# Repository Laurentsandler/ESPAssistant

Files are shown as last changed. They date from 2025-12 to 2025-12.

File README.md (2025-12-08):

# ESPAssistant

A small portable AI Assistant computer built with ESP32.

## Description

This compact computer is equipped with an ESP32 Seed Studio microcontroller, featuring three buttons, a small OLED display, and an INMP441 microphone. It connects to a smartphone's hotspot. Upon pressing and holding one of the buttons, it records audio, which is then transcribed using the Groq Whisper API and sent to the Groq Llama 3.1 API for a chat response. The response is displayed on the OLED screen.

## My motiviation:
So, I wanted a small little computer that will help me throughout the day.

I wanted it to have AI. And also an input using a microphone and some buttons and a small display.

I am in school, so I wanted it to help me track assignments as they come in from my teachers. So, I want to when I press a button, it will record my voice, transcribe it, and then have it sent to a custom website to be added to my assignments or notes, etc.

## Hardware Design

The custom PCB was designed using EasyEDA. Below are the 3D renders and PCB layout:

### PCB Layout

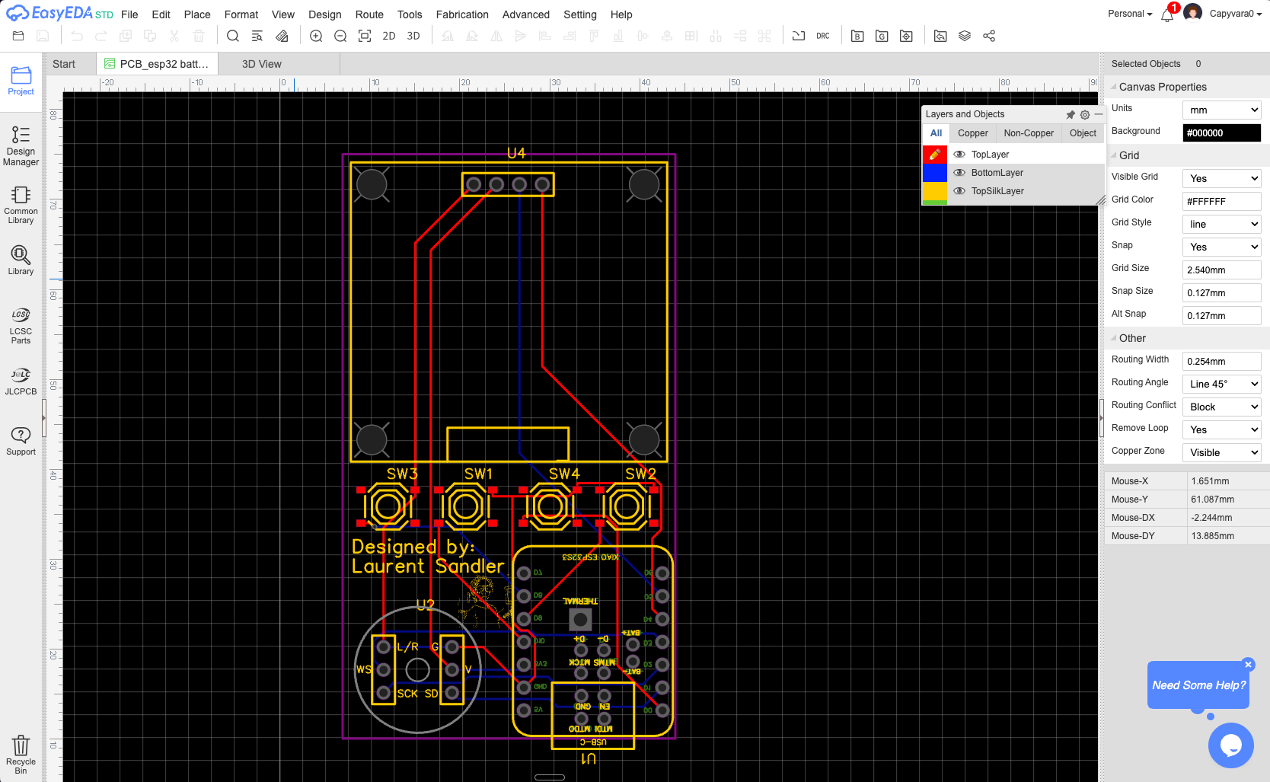
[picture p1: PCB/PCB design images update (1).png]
PCB view


### 3D Renders

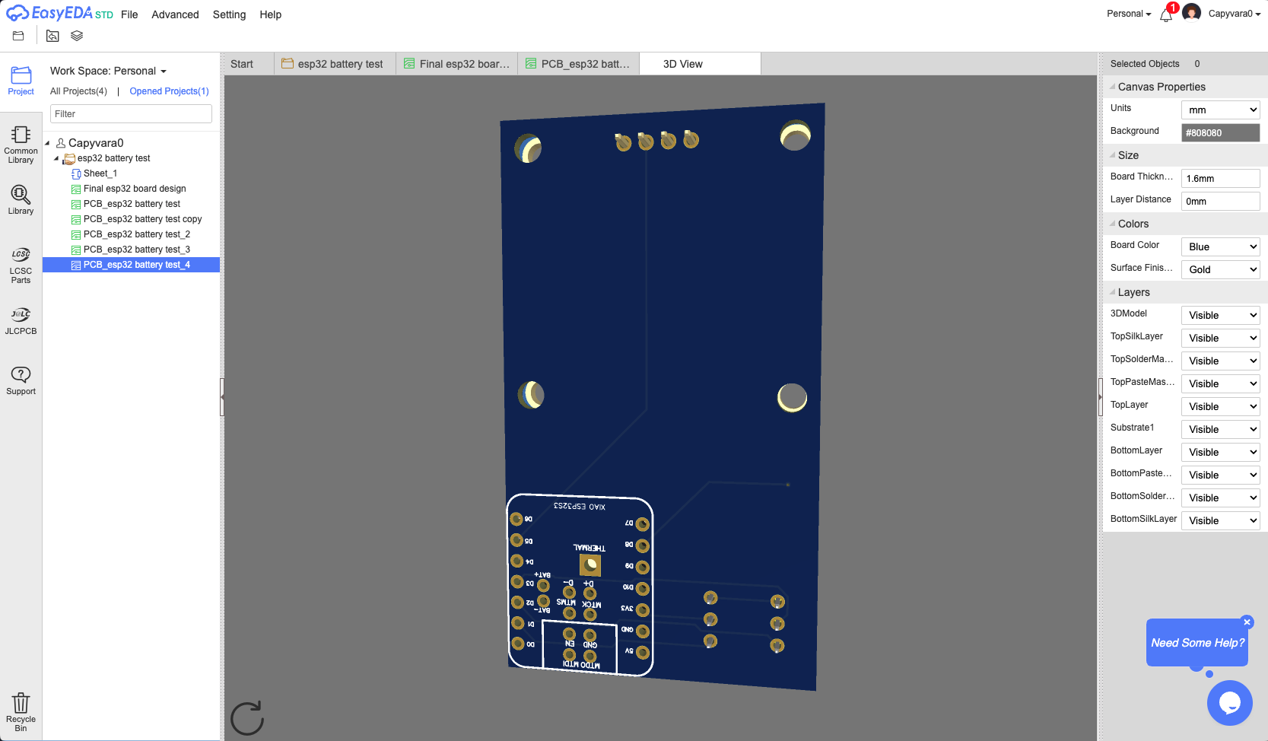
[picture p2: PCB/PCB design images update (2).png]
PCB 3D View - Back Angle


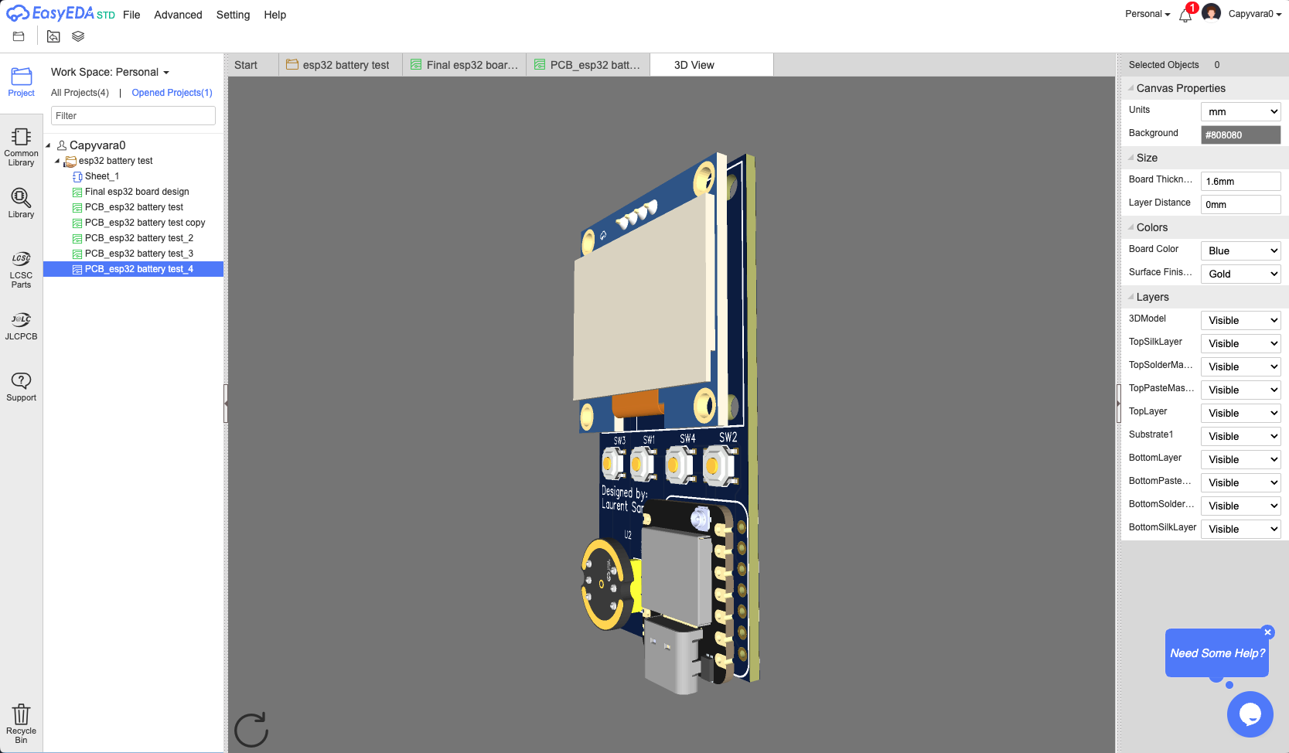
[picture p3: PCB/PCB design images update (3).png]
PCB 3D View - Side


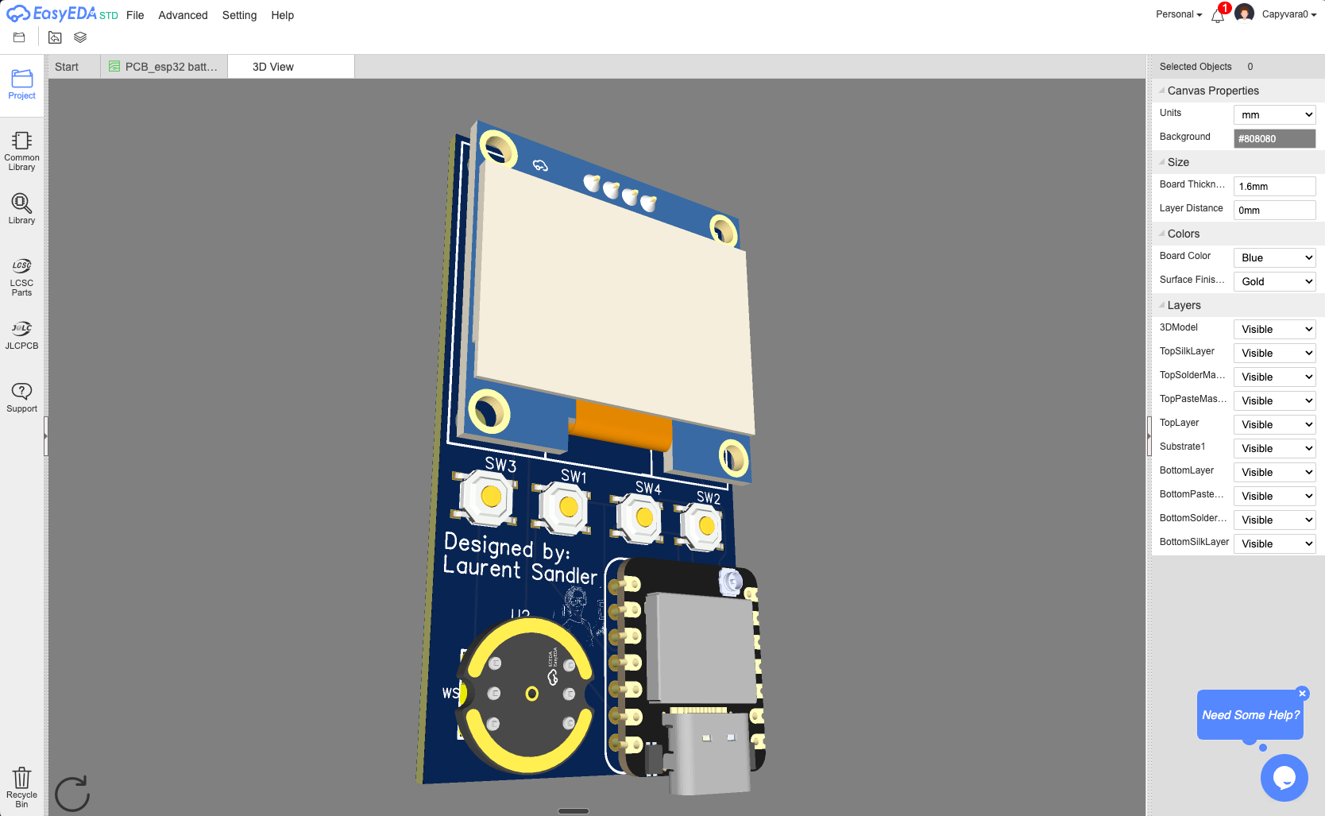
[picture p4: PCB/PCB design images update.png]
PCB 3D View - Front


## Features

- **Voice Recording**: Press and hold to record audio via INMP441 I2S microphone
- **Speech-to-Text**: Transcription via Groq Whisper API
- **AI Chat**: Responses powered by Llama 3.1 via Groq API
- **OLED Display**: 128x64 SH1106/SSD1306 display with modern UI
- **Weather App**: Real-time weather with geolocation
- **Reaction Game**: Fun reaction time game
- **Assignment Tracker**: Voice-record assignments and save to Supabase
- **Screensaver**: Analog clock with digital time display
- **Web Server**: Access recorded audio via browser

## Hardware Requirements

| Component | Specification | Pin Connection |
|---|---|---|
| Microcontroller | ESP32 (Seed Studio) | - |
| Microphone | INMP441 I2S | WS=4, SD=2, SCK=3 |
| Display | SH1106/SSD1306 128x64 OLED | SDA=5, SCL=6 |
| Button 1 (Main) | Momentary push button | GPIO 7 |
| Button 2 (Scroll) | Momentary push button | GPIO 8 |
| Button 3 (Assignment) | Momentary push button | GPIO 9 |
| Button 4 (Extra) | Momentary push button | GPIO 1 |

## Software Dependencies

Install these libraries via Arduino IDE Library Manager:
- WiFi (built-in)
- WiFiClientSecure (built-in)
- HTTPClient (built-in)
- WebServer (built-in)
- ESPmDNS (built-in)
- U8g2lib
- Wire (built-in)

## Configuration

Before uploading, edit the following in `Firmware/sketch.ino`:

```cpp
const char* WIFI_SSID = "YOUR_WIFI_SSID";
const char* WIFI_PASS = "YOUR_WIFI_PASSWORD";
const char* GROQ_API_KEY = "YOUR_GROQ_API_KEY";

const char* SUPABASE_URL = "YOUR_SUPABASE_URL";
const char* SUPABASE_ANON_KEY = "YOUR_SUPABASE_ANON_KEY";
const char* SUPABASE_USER_ID = "YOUR_SUPABASE_USER_ID";
const char* SUPABASE_SERVICE_KEY = "YOUR_SUPABASE_SERVICE_KEY";
```

## Usage

### Menu Navigation
- **Short press Button 1 (GPIO 7)**: Navigate left in menu
- **Short press Button 2 (GPIO 8)**: Navigate right in menu
- **Long press Button 1**: Select/Enter app

### AI Mode
- **Hold Button 1**: Record audio
- **Release**: Transcribe and get AI response
- **Button 2**: Scroll through long responses
- **Long press Button 2**: Return to menu

### Weather Mode
- Automatically fetches weather based on IP geolocation
- **Short press Button 2**: Force refresh
- **Long press Button 1**: Return to menu

### Assignment Mode
- **Hold Button 3 (GPIO 9)**: Record assignment details
- Voice input is parsed by AI and saved to Supabase

## Web Interface

After connecting to WiFi, access the web interface at:
- `http://<ESP32_IP>/` - Home page
- `http://<ESP32_IP>/audio.wav` - Download last recording
- `http://esp32.local/audio.wav` - Via mDNS (if supported)

## API Services Used

- **Groq API**: Speech-to-text (Whisper) and chat (Llama 3.1)
- **Open-Meteo API**: Weather data
- **ipapi.co**: IP-based geolocation
- **Supabase**: Database for assignment storage

## Case
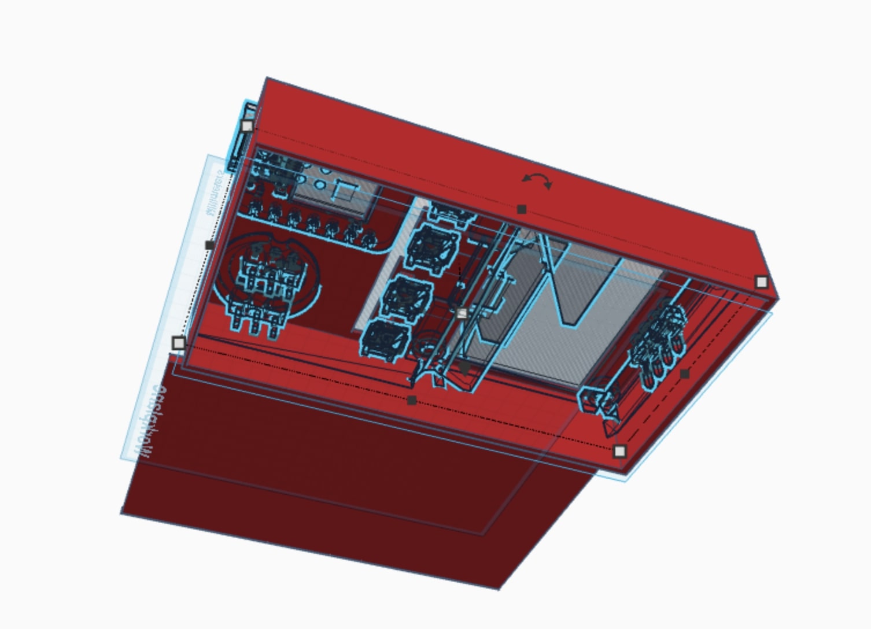
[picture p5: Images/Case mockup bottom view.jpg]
Case mockup bottom view.jpg

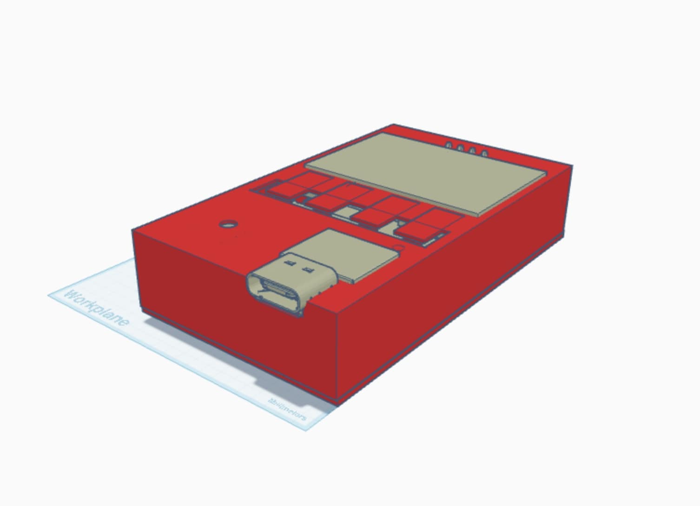
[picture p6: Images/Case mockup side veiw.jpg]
Case mockup side veiw.jpg

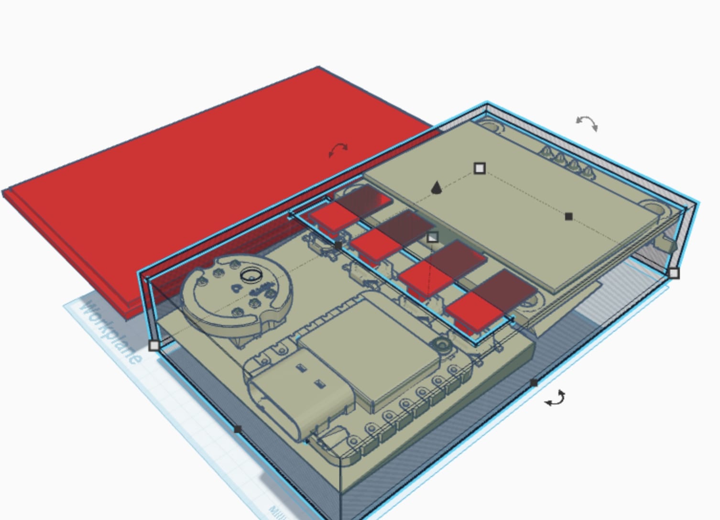
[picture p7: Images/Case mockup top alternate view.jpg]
Case mockup top alternate view.jpg

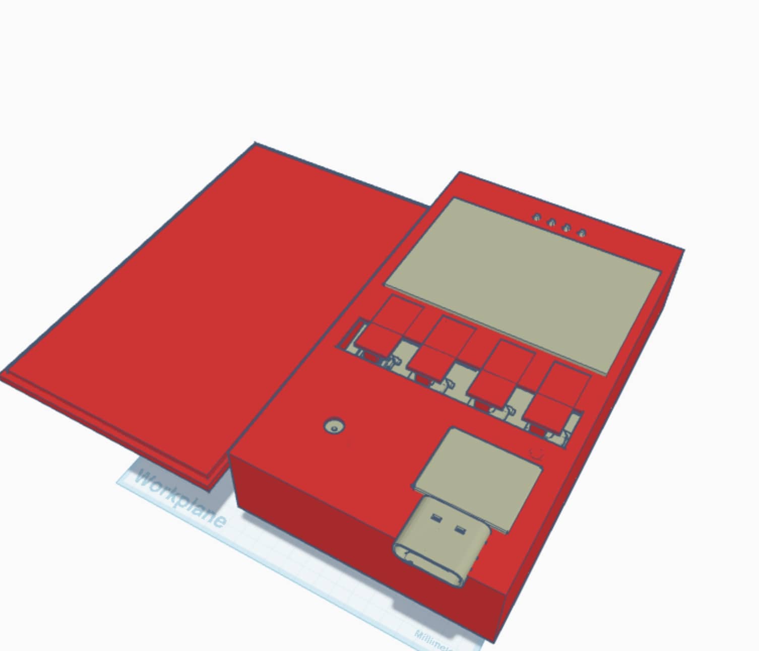
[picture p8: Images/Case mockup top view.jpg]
Case mockup top view.jpg


## Bom: 
| Component | Footprint | Quantity | Supplier Part Number | Price | Link |
| --- | --- | --- | --- | ----- | --- |
| OLED SD130 | OLED-TH12864 | 1 | C9900014198 | 10€ | [https://amzn.eu/d/837vRA1](https://amzn.eu/d/837vRA1) |
| INMP441-MEMS-I2S-MIC-MODULE | INMP441-MEMS-I2S-MIC-MODULE | 1 | N/A | 7€ | [https://amzn.eu/d/0Qtf1CE](https://amzn.eu/d/0Qtf1CE) |
| SEEED XIAO ESP32S3 | SEEED STUDIO XIAO_S3 BY LAURENT | 1 | N/A | 20€ | [https://amzn.eu/d/1FE54ig](https://amzn.eu/d/1FE54ig) |
| TS-1187A-B-A-B | SW-SMD_4P-L5.1-W5.1-P3.70-LS6.5-TL_H1.5 | 4 | C318884 | 0.32€ | [https://www.lcsc.com/product-detail/C318884.html?s_z=n_TS-1187A-B-A-B](https://www.lcsc.com/product-detail/C318884.html?s_z=n_TS-1187A-B-A-B) |
| 500175140 PogoPin Connector | N/A | 1 | B09STS5YZX | 7.90€ | [https://amzn.eu/d/2DIAPW8](https://amzn.eu/d/2DIAPW8) |

## License

MIT License

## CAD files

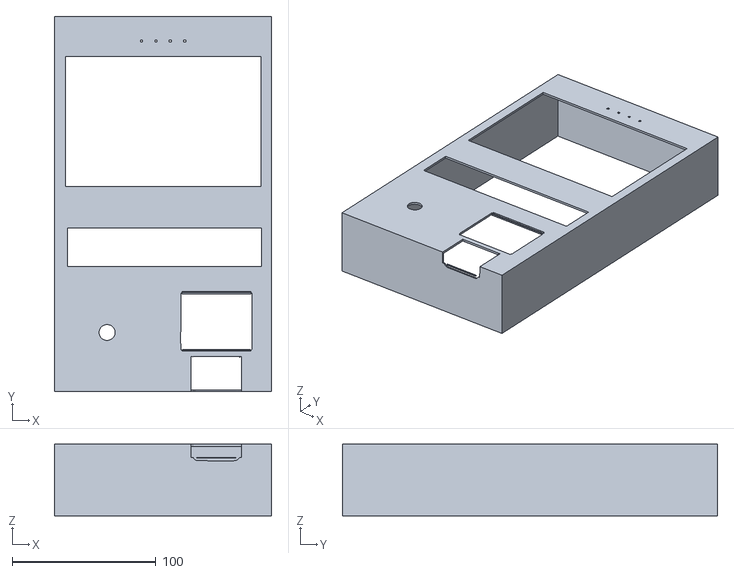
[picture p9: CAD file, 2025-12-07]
CAD/Case with space for battery.stl
151.0 x 261.0 x 50.0

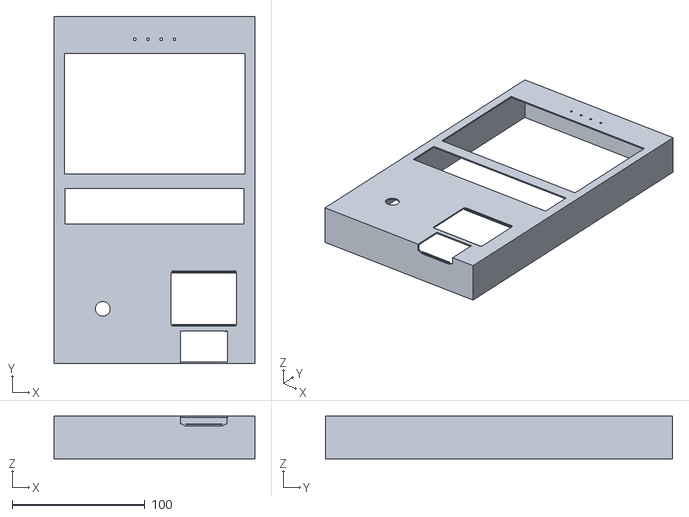
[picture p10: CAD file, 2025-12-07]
CAD/Case.stl
151.0 x 261.0 x 32.0

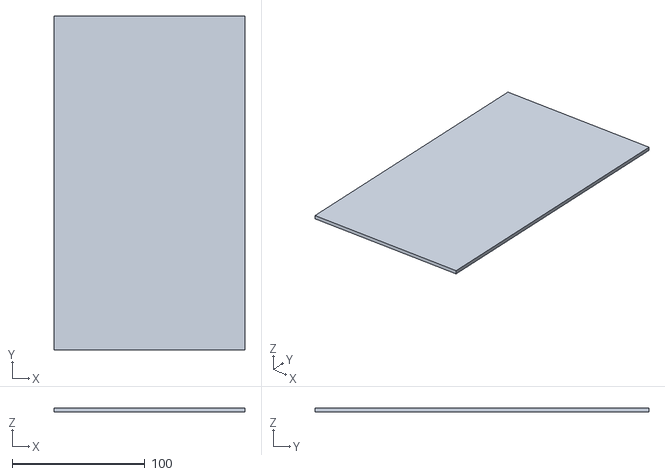
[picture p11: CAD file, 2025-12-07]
CAD/Case lid.stl
144.0 x 252.0 x 3.00

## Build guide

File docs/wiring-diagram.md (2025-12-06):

# Wiring Diagram

This document describes the hardware connections for the ESP32 AI Assistant.

## Component Connections

### INMP441 I2S Microphone
Connect the INMP441 microphone to the ESP32 as follows:

```
INMP441 Pin  →  ESP32 Pin
--------------------------
VDD          →  3.3V
GND          →  GND
WS (Word Select) → GPIO 4
SD (Serial Data) → GPIO 2
SCK (Serial Clock) → GPIO 3
L/R          →  GND (for left channel)
```

### SH1106/SSD1306 OLED Display (I2C)
Connect the 128x64 OLED display to the ESP32:

```
OLED Pin  →  ESP32 Pin
-----------------------
VCC       →  3.3V
GND       →  GND
SDA       →  GPIO 5
SCL       →  GPIO 6
```

### Buttons
Connect momentary push buttons with internal pull-up resistors:

```
Button          →  ESP32 Pin  →  Function
-------------------------------------------
Button 1        →  GPIO 7     →  Main button (menu navigation, recording)
Button 2        →  GPIO 8     →  Scroll button (menu navigation, scrolling)
Button 3        →  GPIO 9     →  Assignment button (voice assignments)
Button 4        →  GPIO 1     →  Extra button (reserved for future use)
```

Each button should connect:
- One side to the GPIO pin
- Other side to GND
- The ESP32 will use INPUT_PULLUP mode (no external resistor needed)

## Circuit Diagram (ASCII Art)

```
                    ┌─────────────────────┐
                    │                     │
    INMP441         │     ESP32-C3        │        SH1106 OLED
    ┌──────┐        │   Seed Studio       │         ┌────────┐
    │ VDD  ├────────┤ 3.3V                │         │  VCC   │
    │ GND  ├────────┤ GND         GPIO 5  ├─────────┤  SDA   │
    │ WS   ├────────┤ GPIO 4      GPIO 6  ├─────────┤  SCL   │
    │ SD   ├────────┤ GPIO 2              │         │  GND   │
    │ SCK  ├────────┤ GPIO 3              │         └────────┘
    │ L/R  ├────┐   │                     │
    └──────┘    │   │                     │
                │   │                     │
               GND  │                     │
                    │                     │
                    │  GPIO 7 ├───[BTN1]──┤ GND
                    │  GPIO 8 ├───[BTN2]──┤ GND
                    │  GPIO 9 ├───[BTN3]──┤ GND
                    │  GPIO 1 ├───[BTN4]──┤ GND
                    │                     │
                    └─────────────────────┘
```

## Power Supply

- The ESP32 can be powered via USB-C (if your board has USB-C) or Micro-USB
- All components (INMP441, OLED) are powered from the ESP32's 3.3V regulator
- Ensure your power supply can provide at least 500mA for stable operation

## Notes

- The INMP441 L/R pin is connected to GND to select the left channel
- All buttons use the ESP32's internal pull-up resistors (INPUT_PULLUP mode)
- I2C address for the OLED is typically 0x3C (defined in the code)
- Ensure proper grounding - connect all GND pins together

## Testing the Hardware

After wiring, you can test each component:

1. **OLED Display**: Upload the sketch and check if the initialization screen appears
2. **Buttons**: Press each button and check the Serial Monitor for debug output
3. **Microphone**: Try recording in AI mode and check the serial output for sample count
4. **WiFi**: Verify connection on the OLED and check the IP address on Serial Monitor

## Troubleshooting

| Issue | Possible Cause | Solution |
|---|---|---|
| OLED not displaying | Wrong I2C address or wiring | Check I2C scanner, verify SDA/SCL pins |
| No audio recording | Incorrect I2S pins | Verify WS, SD, SCK connections |
| Buttons not responding | Pull-up not enabled | Check pinMode(pin, INPUT_PULLUP) in code |
| WiFi not connecting | Wrong credentials | Update WIFI_SSID and WIFI_PASS |

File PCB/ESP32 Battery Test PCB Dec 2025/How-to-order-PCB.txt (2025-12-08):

How to Order PCB

Please refer to:
https://docs.easyeda.com/en/PCB/Order-PCB

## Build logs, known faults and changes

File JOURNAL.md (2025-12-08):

# Development Journal

**Total Time Spent: 16.9 hours**

---

## December 7, 2025
I designed a case and included space for a small battery, a couple of millimeters thick, and some flexible pieces on the case to push the buttons. Some photographs are attached below. And I added the STL files to the repository.

**Files added:**
- `Case with space for battery.stl`
- `Case lid.stl`
- Case mockup images in the Images folder

Case mockup bottom view
Case mockup side view
Case mockup top alternate view
Case mockup top view

---

## ~5 days ago - Finalizing and getting PCB manufactured (2.0 hours)

I finalized the PCB I added a fourth button and made all of the buttons low-profile ones. And remove the expandable I/O. I considered using a small I/O expansion chip, but since this was my first time making a PCB, I wanted it to be as simple as possible. So I decided against that.

I should get the PCB in 5-6 days. Once I get it, I'll solder on the components. In the meantime, I'll need to finish writing the code for it and designing a custom UI.

---

## ~18 days ago - Tested circuit with new board (1.3 hours)

Today my Seeed Studio XIAO ESP32S3 board finally arrived. It came in this small little tiny package. So I connected it to all my components on a breadboard and uploaded the code. But some things didn't work. Turns out the seeed studio board has a different configuration than my other ESP32 dev kit. So I changed that, and once I changed it, everything worked without problems. Also, I noticed that the upload speed on this board is way faster. It can upload stuff a lot faster than my other board.

---

## ~19 days ago - Redesigned the PCB (2.0 hours)

Today I decided to redesign the PCB a little bit because first I realized that it was gonna be pretty hard to directly solder on the microcontroller onto the PCB instead of just using pins. So I redesigned it to use holes where I can put pins in, and then the microcontroller on top to connect it to the PCB. Also, I got some inspiration from another mini computer I saw on Instagram, they also had a Kick starter:

I saw that it has really easy expandable gpio at the top, which I thought would be really nice to have incase i wanted to connect some servos or maybe a temp/humidity sensor. I wanted to use a right angled female socket connector, but sadly jlcpcba did not have any in their library of parts, and I didn't want to solder this one on myself. So I settled on a low-profile flat design. Which JLC PCBA had in stock.

I will definitely take more inspiration from this really cool product. Maybe I'll add the little pogo pin connector at the back.

---

## ~20 days ago - Designing the PCB (4.0 hours)

While the component was shipping, I set out to design my PCB so the whole construction would be smaller. I used easyeda to design the PCB.

Once I get the small microcontroller and test out the circuit on the breadboard and make sure it works, I will have JLC PCB manufacture the PCB.

---

## ~20 days ago - Researching for smaller components (0.5 hours)

Although this design worked, it was way too big to be practical. So I wanted to make it a lot smaller, but with my current ESP32 dev board and my current setup, it was just too big.

So I set out to find a smaller microcontroller.

I researched for a small esp32 microcontroller that I can use, as I am familiar with esp32 boards. I found the Seeed Studio XIAO ESP32 S3 board, it is really small! I found out that it has a built in charging circut, so I will not need an external one, thats good news I planned that the parts I will need are as follows: - A small INMP441 microphone - A small 3.9 diagonal OLED screen - Three small buttons I already have all of these components. Except the microcontroller which I ordered on Amazon.
---

## ~20 days ago - Designed and 3D printed prototype (2.0 hours)

I wanted to test how the prototype worked in the real world, I designed a case for it in on shape. I had put all the components in the case once I 3D printed it and took it with me on my day. It was really useful and without stopping, the battery lasted about 11.5 hours, so
the concept was proven.
---

## ~20 days ago - Built Large prototype (5.0 hours)

Built a working prototype using the parts I already had, and I then programmed it. It has:

A small battery
A PMS board
A microphone
Two buttons
An OLED display
An ESP32 dev board All connected to a proto board.
It successfully recorded my speech, transcribed it, sent it to AI, and then showed me the response back.

---

## ~20 days ago - Making the idea (0.1 hours)

So, I wanted a small little computer that will help me throughout the day.

I wanted it to have AI. And also an input using a microphone and some buttons and a small display.

I am in school, so I wanted it to help me track assignments as they come in from my teachers. So, I want to when I press a button, it will record my voice, transcribe it, and then have it sent to a custom website to be added to my assignments or notes, etc.

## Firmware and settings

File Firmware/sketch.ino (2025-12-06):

/* ESP32 I2S Mic -> Groq Whisper -> Groq Chat -> OLED
  Includes web server for audio playback.
  Hardware:
  - I2S mic (INMP441): WS=4, SD=2, SCK=3
  - OLED SH1106/SSD1306 I2C: SDA=5, SCL=6 (128x64)
  - Button on pin 7 (INPUT_PULLUP)
  - Button on pin 8 (scroll)
  - Button on pin 9 (assignment)
  - Button on pin 1 (extra)
*/

#include <WiFi.h>
#include <WiFiClientSecure.h>
#include <HTTPClient.h>
#include <WebServer.h>
#include <ESPmDNS.h>

#include <driver/i2s.h>
#include <Wire.h>
#include <U8g2lib.h>
#include <stdlib.h>
#include <time.h>
#include <math.h>

// --------- USER CONFIG ----------
const char* WIFI_SSID = "YOUR_WIFI_SSID";
const char* WIFI_PASS = "YOUR_WIFI_PASSWORD";
const char* GROQ_API_KEY = "YOUR_GROQ_API_KEY";

const char* TRANSCRIBE_MODEL = "whisper-large-v3";
const char* CHAT_MODEL = "llama-3.1-8b-instant";

// Supabase config - REPLACE WITH YOUR VALUES!
const char* SUPABASE_URL = "YOUR_SUPABASE_URL";
const char* SUPABASE_ANON_KEY = "YOUR_SUPABASE_ANON_KEY";
const char* SUPABASE_USER_ID = "YOUR_SUPABASE_USER_ID";
const char* SUPABASE_SERVICE_KEY = "YOUR_SUPABASE_SERVICE_KEY";

// Pin definitions
#define I2S_WS 4
#define I2S_SD 2
#define I2S_SCK 3
#define BUTTON_PIN 7
#define BUTTON_SCROLL_PIN 8
#define BUTTON_ASSIGNMENT_PIN 9
#define BUTTON_EXTRA_PIN 1

#define SCREEN_WIDTH 128
#define SCREEN_HEIGHT 64
#define OLED_SDA_PIN 5
#define OLED_SCL_PIN 6
#define OLED_ADDR 0x3C

// UI layout constants
static const int UI_STATUS_H = 12;
static const int UI_BOTTOM_TAB_H = 16;
static const int UI_MARGIN = 4;

// NTP/Time configuration (set to Europe/Paris for Marseille: CET/CEST with DST)
const char* NTP_SERVER_1 = "pool.ntp.org";
const char* NTP_SERVER_2 = "time.nist.gov";
const char* TZ_INFO = "CET-1CEST,M3.5.0/2,M10.5.0/3";

// Create display object for SH1106
U8G2_SH1106_128X64_NONAME_F_HW_I2C u8g2(U8G2_R0, U8X8_PIN_NONE, OLED_SCL_PIN, OLED_SDA_PIN);

// I2S configuration
#define I2S_PORT I2S_NUM_0
#define SAMPLE_RATE 16000
#define BITS_PER_SAMPLE I2S_BITS_PER_SAMPLE_32BIT
#define DMA_BUF_COUNT 8
#define DMA_BUF_LEN 1024

// Recording buffer
const int MAX_RECORD_TIME_MS = 10000;
const int MAX_RECORD_SAMPLES = (SAMPLE_RATE * MAX_RECORD_TIME_MS) / 1000;
int16_t* audioBuffer = nullptr;
int audioSampleCount = 0;

// Web server
WebServer server(80);

// App states
enum AppMode {
  MODE_MENU,
  MODE_AI,
  MODE_WEATHER,
  MODE_ASSIGNMENTS,
  MODE_GAME,
  MODE_SCREENSAVER
};

AppMode currentMode = MODE_SCREENSAVER;
int menuSelection = 0;
const int MENU_ITEMS = 5;
const char* menuLabels[] = {"AI", "Weather", "Assign", "Game", "Clock"};

// AI response storage
String aiResponse = "";
int responseScrollOffset = 0;

// Weather data
String weatherLocation = "";
String weatherTemp = "";
String weatherCondition = "";
unsigned long lastWeatherUpdate = 0;

// Game state
unsigned long gameStartTime = 0;
unsigned long gameReactionTime = 0;
bool gameWaitingForPress = false;

// Assignment recording
bool recordingAssignment = false;

// Button debouncing
unsigned long lastButtonPress = 0;
unsigned long lastScrollPress = 0;
unsigned long lastAssignmentPress = 0;
const int DEBOUNCE_DELAY = 50;
const int LONG_PRESS_DELAY = 500;

// Screensaver
unsigned long lastActivityTime = 0;
const unsigned long SCREENSAVER_TIMEOUT = 60000; // 1 minute

// Function declarations
void setupI2S();
void setupWiFi();
void setupWebServer();
void setupDisplay();
void setupNTP();
void recordAudio();
String transcribeAudio();
String getChatResponse(String userMessage);
void updateWeather();
void fetchWeatherData();
void startReactionGame();
void handleReactionPress();
void saveAssignment(String assignmentText);
void drawMenu();
void drawAIMode();
void drawWeatherMode();
void drawAssignmentMode();
void drawGameMode();
void drawScreensaver();
void drawStatusBar();
void checkButtons();
void returnToMenu();
String urlEncode(String str);
String createMultipartBoundary();
String jsonEscape(String str);

void setup() {
  Serial.begin(115200);
  delay(1000);
  Serial.println("ESP32 AI Assistant Starting...");

  // Initialize buttons
  pinMode(BUTTON_PIN, INPUT_PULLUP);
  pinMode(BUTTON_SCROLL_PIN, INPUT_PULLUP);
  pinMode(BUTTON_ASSIGNMENT_PIN, INPUT_PULLUP);
  pinMode(BUTTON_EXTRA_PIN, INPUT_PULLUP);

  // Initialize display
  setupDisplay();
  u8g2.clearBuffer();
  u8g2.setFont(u8g2_font_6x10_tr);
  u8g2.drawStr(0, 20, "Initializing...");
  u8g2.sendBuffer();

  // Allocate audio buffer with overflow protection
  size_t bufferSize = (size_t)MAX_RECORD_SAMPLES * sizeof(int16_t);
  // Check for overflow: if the result is smaller than MAX_RECORD_SAMPLES, overflow occurred
  if (bufferSize / sizeof(int16_t) != MAX_RECORD_SAMPLES) {
    Serial.println("Buffer size overflow detected!");
    u8g2.clearBuffer();
    u8g2.drawStr(0, 20, "Config Error!");
    u8g2.sendBuffer();
    while (1) delay(1000);
  }
  audioBuffer = (int16_t*)malloc(bufferSize);
  if (!audioBuffer) {
    Serial.println("Failed to allocate audio buffer!");
    u8g2.clearBuffer();
    u8g2.drawStr(0, 20, "Memory Error!");
    u8g2.sendBuffer();
    while (1) delay(1000);
  }

  // Setup I2S
  setupI2S();

  // Connect to WiFi
  setupWiFi();

  // Setup NTP
  setupNTP();

  // Setup web server
  setupWebServer();

  // Start in screensaver mode
  currentMode = MODE_SCREENSAVER;
  lastActivityTime = millis();

  Serial.println("Setup complete!");
}

void loop() {
  server.handleClient();
  checkButtons();

  // Auto-enter screensaver after timeout
  if (currentMode != MODE_SCREENSAVER && (millis() - lastActivityTime > SCREENSAVER_TIMEOUT)) {
    currentMode = MODE_SCREENSAVER;
  }

  // Draw current mode
  u8g2.clearBuffer();
  
  switch (currentMode) {
    case MODE_MENU:
      drawMenu();
      break;
    case MODE_AI:
      drawAIMode();
      break;
    case MODE_WEATHER:
      drawWeatherMode();
      break;
    case MODE_ASSIGNMENTS:
      drawAssignmentMode();
      break;
    case MODE_GAME:
      drawGameMode();
      break;
    case MODE_SCREENSAVER:
      drawScreensaver();
      break;
  }

  u8g2.sendBuffer();
  delay(10);
}

void setupDisplay() {
  Wire.begin(OLED_SDA_PIN, OLED_SCL_PIN);
  u8g2.begin();
  u8g2.setContrast(255);
}

void setupI2S() {
  i2s_config_t i2s_config = {
    .mode = (i2s_mode_t)(I2S_MODE_MASTER | I2S_MODE_RX),
    .sample_rate = SAMPLE_RATE,
    .bits_per_sample = BITS_PER_SAMPLE,
    .channel_format = I2S_CHANNEL_FMT_ONLY_LEFT,
    .communication_format = I2S_COMM_FORMAT_I2S,
    .intr_alloc_flags = ESP_INTR_FLAG_LEVEL1,
    .dma_buf_count = DMA_BUF_COUNT,
    .dma_buf_len = DMA_BUF_LEN,
    .use_apll = false,
    .tx_desc_auto_clear = false,
    .fixed_mclk = 0
  };

  i2s_pin_config_t pin_config = {
    .bck_io_num = I2S_SCK,
    .ws_io_num = I2S_WS,
    .data_out_num = I2S_PIN_NO_CHANGE,
    .data_in_num = I2S_SD
  };

  i2s_driver_install(I2S_PORT, &i2s_config, 0, NULL);
  i2s_set_pin(I2S_PORT, &pin_config);
  Serial.println("I2S initialized");
}

void setupWiFi() {
  WiFi.begin(WIFI_SSID, WIFI_PASS);
  Serial.print("Connecting to WiFi");
  
  int attempt = 0;
  while (WiFi.status() != WL_CONNECTED && attempt < 20) {
    delay(500);
    Serial.print(".");
    u8g2.clearBuffer();
    u8g2.setFont(u8g2_font_6x10_tr);
    u8g2.drawStr(0, 20, "Connecting WiFi");
    String dots = "";
    for (int i = 0; i < (attempt % 4); i++) dots += ".";
    u8g2.drawStr(0, 35, dots.c_str());
    u8g2.sendBuffer();
    attempt++;
  }

  if (WiFi.status() == WL_CONNECTED) {
    Serial.println("\nWiFi connected!");
    Serial.print("IP: ");
    Serial.println(WiFi.localIP());
  } else {
    Serial.println("\nWiFi connection failed!");
  }
}

void setupNTP() {
  configTime(0, 0, NTP_SERVER_1, NTP_SERVER_2);
  setenv("TZ", TZ_INFO, 1);
  tzset();
  Serial.println("NTP configured");
}

void setupWebServer() {
  // mDNS responder
  if (MDNS.begin("esp32")) {
    Serial.println("mDNS responder started: esp32.local");
  }

  server.on("/", HTTP_GET, []() {
    String html = "<html><body><h1>ESP32 AI Assistant</h1>";
    html += "<p>IP: " + WiFi.localIP().toString() + "</p>";
    html += "<p><a href='/audio.wav'>Download last recording</a></p>";
    html += "</body></html>";
    server.send(200, "text/html", html);
  });

  server.on("/audio.wav", HTTP_GET, []() {
    if (audioSampleCount == 0) {
      server.send(404, "text/plain", "No recording available");
      return;
    }

    // Create WAV header
    uint32_t dataSize = audioSampleCount * 2;
    uint32_t fileSize = dataSize + 36;
    uint8_t wavHeader[44];
    
    memcpy(wavHeader, "RIFF", 4);
    *(uint32_t*)(wavHeader + 4) = fileSize;
    memcpy(wavHeader + 8, "WAVE", 4);
    memcpy(wavHeader + 12, "fmt ", 4);
    *(uint32_t*)(wavHeader + 16) = 16;
    *(uint16_t*)(wavHeader + 20) = 1;
    *(uint16_t*)(wavHeader + 22) = 1;
    *(uint32_t*)(wavHeader + 24) = SAMPLE_RATE;
    *(uint32_t*)(wavHeader + 28) = SAMPLE_RATE * 2;
    *(uint16_t*)(wavHeader + 32) = 2;
    *(uint16_t*)(wavHeader + 34) = 16;
    memcpy(wavHeader + 36, "data", 4);
    *(uint32_t*)(wavHeader + 40) = dataSize;

    server.setContentLength(44 + dataSize);
    server.send(200, "audio/wav", "");
    server.sendContent((const char*)wavHeader, 44);
    server.sendContent((const char*)audioBuffer, dataSize);
  });

  server.begin();
  Serial.println("Web server started");
}

void recordAudio() {
  Serial.println("Recording...");
  audioSampleCount = 0;
  
  unsigned long startTime = millis();
  size_t bytesRead;
  int32_t i2s_data[DMA_BUF_LEN];
  
  while (digitalRead(BUTTON_PIN) == LOW && (millis() - startTime < MAX_RECORD_TIME_MS)) {
    i2s_read(I2S_PORT, &i2s_data, DMA_BUF_LEN * 4, &bytesRead, portMAX_DELAY);
    int samplesRead = bytesRead / 4;
    
    for (int i = 0; i < samplesRead; i++) {
      if (audioSampleCount >= MAX_RECORD_SAMPLES) {
        break;
      }
      audioBuffer[audioSampleCount++] = (int16_t)(i2s_data[i] >> 14);
    }
    
    // Stop if buffer is full
    if (audioSampleCount >= MAX_RECORD_SAMPLES) {
      break;
    }

    u8g2.clearBuffer();
    u8g2.setFont(u8g2_font_6x10_tr);
    u8g2.drawStr(0, 20, "Recording...");
    int duration = (millis() - startTime) / 1000;
    String timeStr = String(duration) + "s";
    u8g2.drawStr(0, 35, timeStr.c_str());
    u8g2.sendBuffer();
  }
  
  Serial.printf("Recorded %d samples\n", audioSampleCount);
}

String transcribeAudio() {
  if (audioSampleCount == 0) return "";
  
  Serial.println("Transcribing...");
  u8g2.clearBuffer();
  u8g2.setFont(u8g2_font_6x10_tr);
  u8g2.drawStr(0, 20, "Transcribing...");
  u8g2.sendBuffer();

  WiFiClientSecure client;
  client.setInsecure();
  HTTPClient https;

  String boundary = createMultipartBoundary();
  
  if (https.begin(client, "https://api.groq.com/openai/v1/audio/transcriptions")) {
    https.addHeader("Authorization", "Bearer " + String(GROQ_API_KEY));
    https.addHeader("Content-Type", "multipart/form-data; boundary=" + boundary);

    String body = "";
    body += "--" + boundary + "\r\n";
    body += "Content-Disposition: form-data; name=\"file\"; filename=\"audio.wav\"\r\n";
    body += "Content-Type: audio/wav\r\n\r\n";

    uint32_t dataSize = audioSampleCount * 2;
    uint32_t fileSize = dataSize + 36;
    uint8_t wavHeader[44];
    
    memcpy(wavHeader, "RIFF", 4);
    *(uint32_t*)(wavHeader + 4) = fileSize;
    memcpy(wavHeader + 8, "WAVE", 4);
    memcpy(wavHeader + 12, "fmt ", 4);
    *(uint32_t*)(wavHeader + 16) = 16;
    *(uint16_t*)(wavHeader + 20) = 1;
    *(uint16_t*)(wavHeader + 22) = 1;
    *(uint32_t*)(wavHeader + 24) = SAMPLE_RATE;
    *(uint32_t*)(wavHeader + 28) = SAMPLE_RATE * 2;
    *(uint16_t*)(wavHeader + 32) = 2;
    *(uint16_t*)(wavHeader + 34) = 16;
    memcpy(wavHeader + 36, "data", 4);
    *(uint32_t*)(wavHeader + 40) = dataSize;

    for (int i = 0; i < 44; i++) body += (char)wavHeader[i];
    for (int i = 0; i < audioSampleCount; i++) {
      body += (char)(audioBuffer[i] & 0xFF);
      body += (char)((audioBuffer[i] >> 8) & 0xFF);
    }

    body += "\r\n--" + boundary + "\r\n";
    body += "Content-Disposition: form-data; name=\"model\"\r\n\r\n";
    body += TRANSCRIBE_MODEL;
    body += "\r\n--" + boundary + "--\r\n";

    int httpCode = https.POST((uint8_t*)body.c_str(), body.length());
    
    if (httpCode == 200) {
      String response = https.getString();
      Serial.println("Transcription response: " + response);
      
      int textStart = response.indexOf("\"text\":\"") + 8;
      int textEnd = response.indexOf("\"", textStart);
      if (textStart > 7 && textEnd > textStart) {
        String text = response.substring(textStart, textEnd);
        https.end();
        return text;
      }
    } else {
      Serial.printf("Transcription failed: %d\n", httpCode);
    }
    https.end();
  }
  
  return "";
}

String getChatResponse(String userMessage) {
  Serial.println("Getting chat response for: " + userMessage);
  
  u8g2.clearBuffer();
  u8g2.setFont(u8g2_font_6x10_tr);
  u8g2.drawStr(0, 20, "AI thinking...");
  u8g2.sendBuffer();

  WiFiClientSecure client;
  client.setInsecure();
  HTTPClient https;

  if (https.begin(client, "https://api.groq.com/openai/v1/chat/completions")) {
    https.addHeader("Authorization", "Bearer " + String(GROQ_API_KEY));
    https.addHeader("Content-Type", "application/json");

    String jsonPayload = "{\"model\":\"" + String(CHAT_MODEL) + "\",";
    jsonPayload += "\"messages\":[{\"role\":\"user\",\"content\":\"" + jsonEscape(userMessage) + "\"}],";
    jsonPayload += "\"max_tokens\":300}";

    int httpCode = https.POST(jsonPayload);
    
    if (httpCode == 200) {
      String response = https.getString();
      Serial.println("Chat response received");
      
      int contentStart = response.indexOf("\"content\":\"") + 11;
      int contentEnd = response.indexOf("\"", contentStart);
      if (contentStart > 10 && contentEnd > contentStart) {
        String content = response.substring(contentStart, contentEnd);
        content.replace("\\n", " ");
        https.end();
        return content;
      }
    } else {
      Serial.printf("Chat request failed: %d\n", httpCode);
    }
    https.end();
  }
  
  return "Error: Could not reach AI";
}

void fetchWeatherData() {
  Serial.println("Fetching weather...");
  
  // First get location from IP
  WiFiClientSecure client;
  client.setInsecure();
  HTTPClient https;
  
  String lat = "";
  String lon = "";
  
  if (https.begin(client, "https://ipapi.co/json/")) {
    int httpCode = https.GET();
    if (httpCode == 200) {
      String response = https.getString();
      
      int cityStart = response.indexOf("\"city\":\"") + 8;
      int cityEnd = response.indexOf("\"", cityStart);
      if (cityStart > 7 && cityEnd > cityStart) {
        weatherLocation = response.substring(cityStart, cityEnd);
      }
      
      int latStart = response.indexOf("\"latitude\":") + 11;
      int latEnd = response.indexOf(",", latStart);
      if (latStart > 10 && latEnd > latStart) {
        lat = response.substring(latStart, latEnd);
      }
      
      int lonStart = response.indexOf("\"longitude\":") + 12;
      int lonEnd = response.indexOf(",", lonStart);
      if (lonStart > 11 && lonEnd > lonStart) {
        lon = response.substring(lonStart, lonEnd);
      }
    }
    https.end();
  }
  
  if (lat.length() > 0 && lon.length() > 0) {
    String weatherUrl = "https://api.open-meteo.com/v1/forecast?latitude=" + lat;
    weatherUrl += "&longitude=" + lon + "&current_weather=true";
    
    if (https.begin(client, weatherUrl)) {
      int httpCode = https.GET();
      if (httpCode == 200) {
        String response = https.getString();
        
        int tempStart = response.indexOf("\"temperature\":") + 14;
        int tempEnd = response.indexOf(",", tempStart);
        if (tempStart > 13 && tempEnd > tempStart) {
          weatherTemp = response.substring(tempStart, tempEnd) + "C";
        }
        
        int codeStart = response.indexOf("\"weathercode\":") + 14;
        int codeEnd = response.indexOf(",", codeStart);
        if (codeStart > 13 && codeEnd > codeStart) {
          int code = response.substring(codeStart, codeEnd).toInt();
          if (code == 0) weatherCondition = "Clear";
          else if (code <= 3) weatherCondition = "Cloudy";
          else if (code <= 67) weatherCondition = "Rainy";
          else if (code <= 77) weatherCondition = "Snowy";
          else weatherCondition = "Stormy";
        }
        
        lastWeatherUpdate = millis();
      }
      https.end();
    }
  }
}

void saveAssignment(String assignmentText) {
  Serial.println("Saving assignment: " + assignmentText);
  
  // First, parse the assignment with AI
  String aiPrompt = "Extract task details from this voice note into JSON format with fields: title, description, due_date (YYYY-MM-DD or null). Voice note: " + assignmentText;
  String aiParsed = getChatResponse(aiPrompt);
  
  // Save to Supabase
  WiFiClientSecure client;
  client.setInsecure();
  HTTPClient https;
  
  String url = String(SUPABASE_URL) + "/rest/v1/assignments";
  
  if (https.begin(client, url)) {
    https.addHeader("apikey", SUPABASE_ANON_KEY);
    https.addHeader("Authorization", "Bearer " + String(SUPABASE_SERVICE_KEY));
    https.addHeader("Content-Type", "application/json");
    https.addHeader("Prefer", "return=minimal");
    
    String payload = "{\"user_id\":\"" + String(SUPABASE_USER_ID) + "\",";
    payload += "\"raw_text\":\"" + jsonEscape(assignmentText) + "\",";
    payload += "\"parsed_data\":" + aiParsed + "}";
    
    int httpCode = https.POST(payload);
    
    if (httpCode == 201 || httpCode == 200) {
      Serial.println("Assignment saved successfully");
    } else {
      Serial.printf("Failed to save assignment: %d\n", httpCode);
    }
    https.end();
  }
}

void startReactionGame() {
  gameWaitingForPress = false;
  gameReactionTime = 0;
  
  // Random delay 1-3 seconds
  unsigned long delayTime = random(1000, 3000);
  gameStartTime = millis() + delayTime;
  
  u8g2.clearBuffer();
  u8g2.setFont(u8g2_font_6x10_tr);
  u8g2.drawStr(0, 30, "Wait for GO!");
  u8g2.sendBuffer();
}

void handleReactionPress() {
  if (gameWaitingForPress) {
    gameReactionTime = millis() - gameStartTime;
    gameWaitingForPress = false;
  }
}

void drawStatusBar() {
  u8g2.setFont(u8g2_font_5x7_tr);
  
  // WiFi status
  if (WiFi.status() == WL_CONNECTED) {
    u8g2.drawStr(0, 8, "WiFi");
  }
  
  // Time
  struct tm timeinfo;
  if (getLocalTime(&timeinfo)) {
    char timeStr[6];
    sprintf(timeStr, "%02d:%02d", timeinfo.tm_hour, timeinfo.tm_min);
    u8g2.drawStr(90, 8, timeStr);
  }
  
  u8g2.drawLine(0, 10, SCREEN_WIDTH, 10);
}

void drawMenu() {
  drawStatusBar();
  
  u8g2.setFont(u8g2_font_6x10_tr);
  u8g2.drawStr(30, 25, "MENU");
  
  int startY = 35;
  for (int i = 0; i < MENU_ITEMS; i++) {
    if (i == menuSelection) {
      u8g2.drawStr(10, startY + (i * 12), ">");
    }
    u8g2.drawStr(20, startY + (i * 12), menuLabels[i]);
  }
  
  u8g2.drawLine(0, SCREEN_HEIGHT - UI_BOTTOM_TAB_H, SCREEN_WIDTH, SCREEN_HEIGHT - UI_BOTTOM_TAB_H);
  u8g2.setFont(u8g2_font_5x7_tr);
  u8g2.drawStr(5, SCREEN_HEIGHT - 3, "Prev");
  u8g2.drawStr(45, SCREEN_HEIGHT - 3, "Next");
  u8g2.drawStr(85, SCREEN_HEIGHT - 3, "Select");
}

void drawAIMode() {
  drawStatusBar();
  
  u8g2.setFont(u8g2_font_6x10_tr);
  u8g2.drawStr(40, 25, "AI MODE");
  
  if (aiResponse.length() > 0) {
    u8g2.setFont(u8g2_font_5x7_tr);
    int y = 35;
    int charWidth = 5;
    int maxCharsPerLine = (SCREEN_WIDTH - 4) / charWidth;
    
    int startIdx = responseScrollOffset * maxCharsPerLine;
    for (int line = 0; line < 3 && startIdx < aiResponse.length(); line++) {
      String lineText = aiResponse.substring(startIdx, min((int)aiResponse.length(), startIdx + maxCharsPerLine));
      u8g2.drawStr(2, y + (line * 10), lineText.c_str());
      startIdx += maxCharsPerLine;
    }
  } else {
    u8g2.setFont(u8g2_font_5x7_tr);
    u8g2.drawStr(5, 40, "Hold button");
    u8g2.drawStr(5, 50, "to record");
  }
  
  u8g2.drawLine(0, SCREEN_HEIGHT - UI_BOTTOM_TAB_H, SCREEN_WIDTH, SCREEN_HEIGHT - UI_BOTTOM_TAB_H);
  u8g2.setFont(u8g2_font_5x7_tr);
  u8g2.drawStr(5, SCREEN_HEIGHT - 3, "Record");
  u8g2.drawStr(45, SCREEN_HEIGHT - 3, "Scroll");
  u8g2.drawStr(85, SCREEN_HEIGHT - 3, "Menu");
}

void drawWeatherMode() {
  drawStatusBar();
  
  u8g2.setFont(u8g2_font_6x10_tr);
  u8g2.drawStr(30, 25, "WEATHER");
  
  if (weatherLocation.length() > 0) {
    u8g2.setFont(u8g2_font_5x7_tr);
    u8g2.drawStr(5, 35, weatherLocation.c_str());
    
    u8g2.setFont(u8g2_font_10x20_tr);
    u8g2.drawStr(5, 52, weatherTemp.c_str());
    
    u8g2.setFont(u8g2_font_6x10_tr);
    u8g2.drawStr(60, 52, weatherCondition.c_str());
  } else {
    u8g2.setFont(u8g2_font_5x7_tr);
    u8g2.drawStr(5, 40, "No data");
  }
  
  u8g2.drawLine(0, SCREEN_HEIGHT - UI_BOTTOM_TAB_H, SCREEN_WIDTH, SCREEN_HEIGHT - UI_BOTTOM_TAB_H);
  u8g2.setFont(u8g2_font_5x7_tr);
  u8g2.drawStr(5, SCREEN_HEIGHT - 3, "Menu");
  u8g2.drawStr(45, SCREEN_HEIGHT - 3, "Refresh");
}

void drawAssignmentMode() {
  drawStatusBar();
  
  u8g2.setFont(u8g2_font_6x10_tr);
  u8g2.drawStr(20, 25, "ASSIGNMENT");
  
  u8g2.setFont(u8g2_font_5x7_tr);
  if (recordingAssignment) {
    u8g2.drawStr(5, 40, "Recording...");
  } else {
    u8g2.drawStr(5, 40, "Hold Btn3 to");
    u8g2.drawStr(5, 50, "record task");
  }
  
  u8g2.drawLine(0, SCREEN_HEIGHT - UI_BOTTOM_TAB_H, SCREEN_WIDTH, SCREEN_HEIGHT - UI_BOTTOM_TAB_H);
  u8g2.setFont(u8g2_font_5x7_tr);
  u8g2.drawStr(5, SCREEN_HEIGHT - 3, "Menu");
}
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

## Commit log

2025-12-06 Add ESP32 AI Assistant complete project setup
2025-12-06 Fix security vulnerabilities: add JSON escaping and buffer overflow protection
    [sketch.ino]
2025-12-06 Add bom.csv file
    [bom.csv]
2025-12-06 Update bom.csv with the latest component information
    [bom.csv]
2025-12-06 Add missing supplier part numbers to BOM
    [bom.csv]
2025-12-06 Add PogoPin Connector to BOM
    [bom.csv]
2025-12-06 Update BOM to include price and supplier links
    Added price and link columns to BOM.
    [bom.csv]
2025-12-06 Rename ESP32 Battery Test Dec 2025 (1).json to ESP32 Easyeda pcb.json
2025-12-06 Rename ESP32 Battery Test Schematic Dec 2025.svg to ESP32 pcb schematic.svg
2025-12-06 Rename ESP32 Battery Test Dec 2025.json to ESP32 Easyeda schematic.json
2025-12-06 Rename ESP32 Battery Test Dec 2025 (1).zip to ESP32 pcb obj(3d).zip
2025-12-06 Update PCB 3D View image in README
2025-12-06 Fix image link for PCB 3D View in README
    Updated image link for PCB 3D View - Front.
2025-12-06 Fix section headings and update PCB images in README
    Updated the README to correct section headings and image placements.
2025-12-07 Rename Frantic Bruticus Juttuli.stl to Case with space for battery.stl
    [Case with space for battery.stl]
2025-12-07 Rename Frantic Bruticus Juttuli (1).stl to Case with space for battery + button pushers
2025-12-07 Rename Frantic Bruticus Juttuli (3).stl to Case with space for battery.stl
    [Case with space for battery.stl]
2025-12-07 Rename Frantic Bruticus Juttuli (2).stl to Case wit space for battery lid.stl
    [Case wit space for battery lid.stl]
2025-12-07 Add case files section to README
    Added a section about the case files included in the repository.
2025-12-07 Rename Case wit space for battery lid.stl to Case with space for battery lid.stl
    [Case with space for battery lid.stl]
2025-12-07 Reorganize repository into PCB, CAD, and Firmware directories
    [Case with space for battery lid.stl, Case with space for battery.stl, bom.csv]
2025-12-07 Rename Case with space for battery.stl to Case.stl
    [Case.stl]
2025-12-07 Rename Case with space for battery lid.stl to Case lid.stl
    [Case lid.stl]
2025-12-07 Rename Frantic Bruticus Juttuli (4).stl to Case with space for batterystl
2025-12-07 Rename Case with space for batterystl to Case with space for battery.stl
    [Case with space for battery.stl]
2025-12-08 Add BOM section to README
    Added a Bill of Materials (BOM) section with components, quantities, suppliers, and prices.
2025-12-08 Refactor BOM section into a markdown table
    Updated BOM section to use a markdown table format for better readability.
2025-12-08 Rename ESP32 Battery Test PCB Dec 2025.csv to Pick and place.csv
    [ESP32 Battery Test PCB Dec 2025.csv, Pick and place.csv]
2025-12-08 Add Drill_NPTH_Through.DRL file
    [Drill_NPTH_Through.DRL]
2025-12-08 Add drill file for ESP32 Battery Test PCB
2025-12-08 Revise journal entries for clarity and detail
    Updated journal entries to improve clarity and detail, including design changes for the PCB and case, testing results, and component specifications.
